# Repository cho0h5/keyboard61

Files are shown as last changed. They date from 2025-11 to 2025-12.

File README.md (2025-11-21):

# Keyboard Project

## Schematic

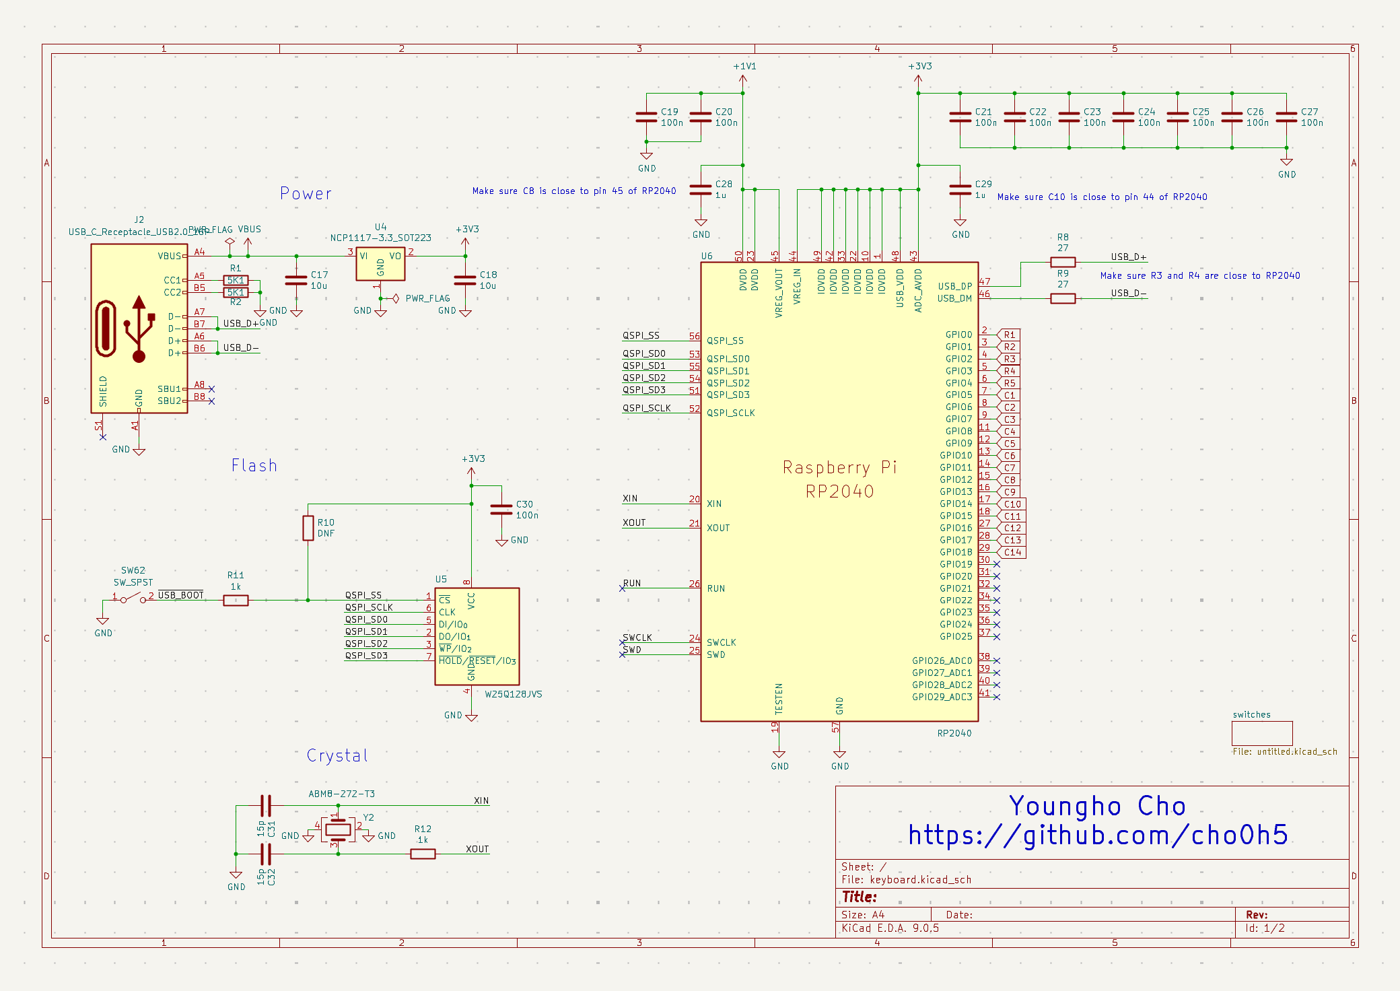
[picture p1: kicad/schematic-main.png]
Keyboard Schematic

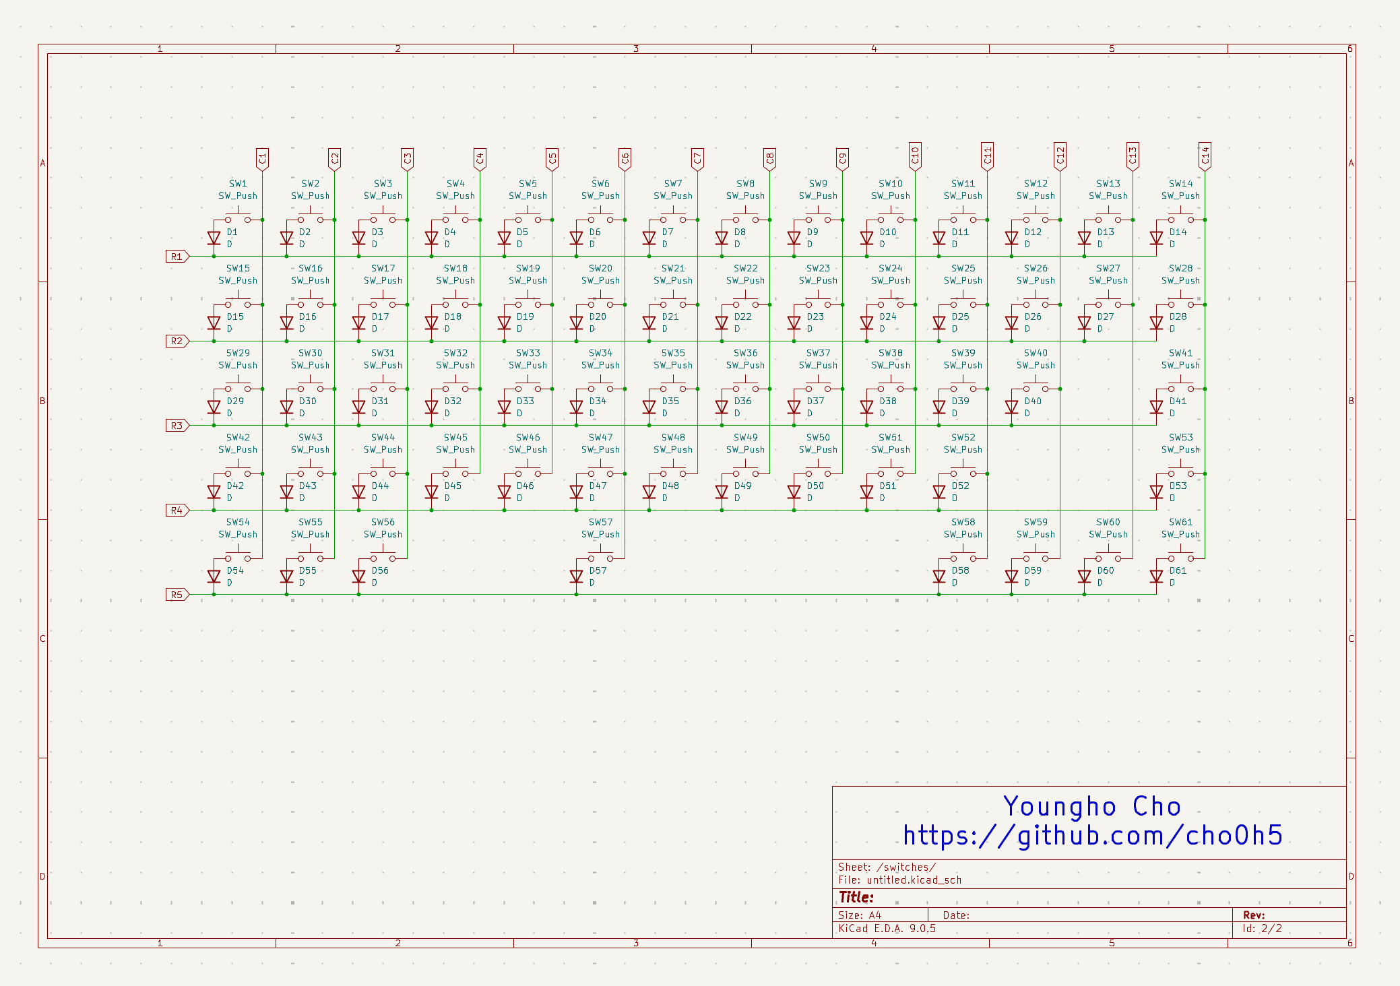
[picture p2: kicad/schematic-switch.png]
Keyboard Switches


## PCB Layout

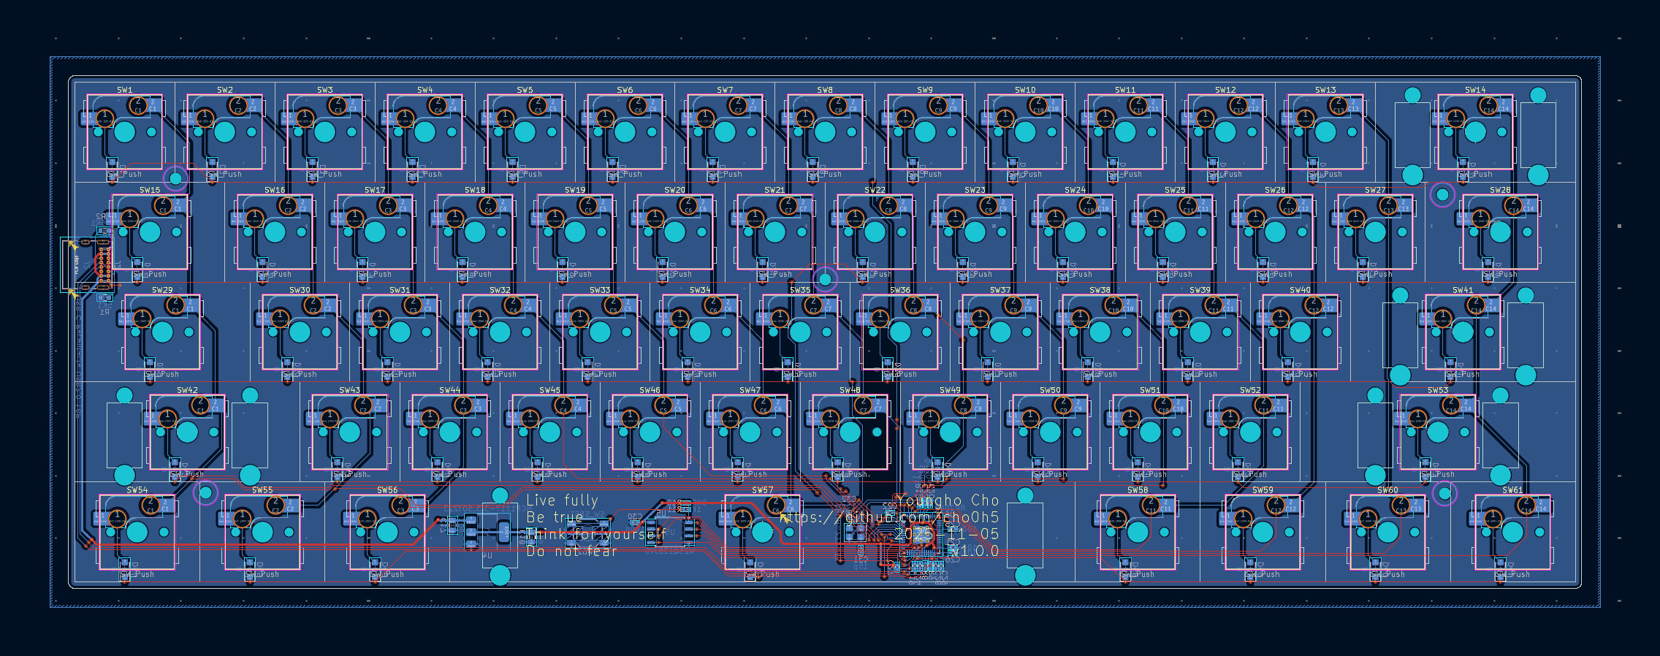
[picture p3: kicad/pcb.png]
PCB


## 3D Rendering

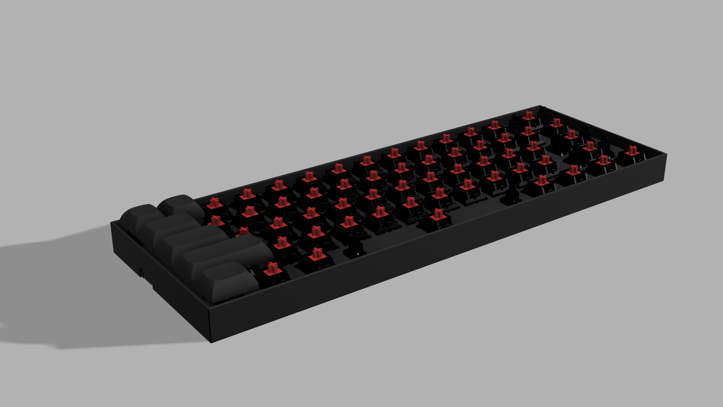
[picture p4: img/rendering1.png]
Rendering 1

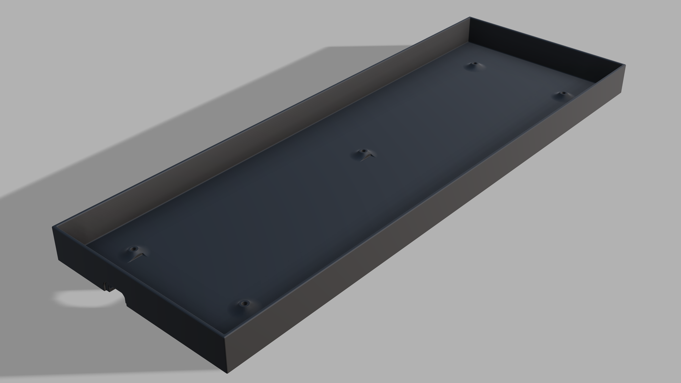
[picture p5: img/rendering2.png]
Rendering 2

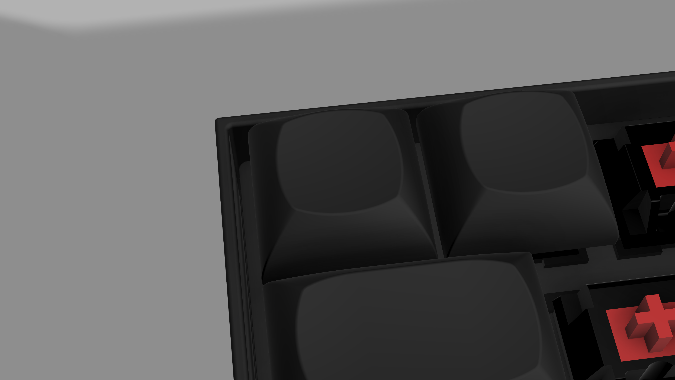
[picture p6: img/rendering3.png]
Rendering 3

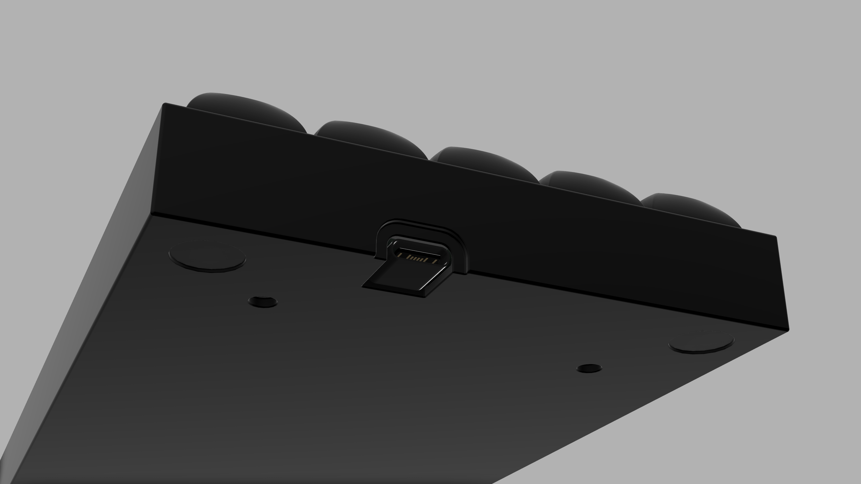
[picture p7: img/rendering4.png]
Rendering 4

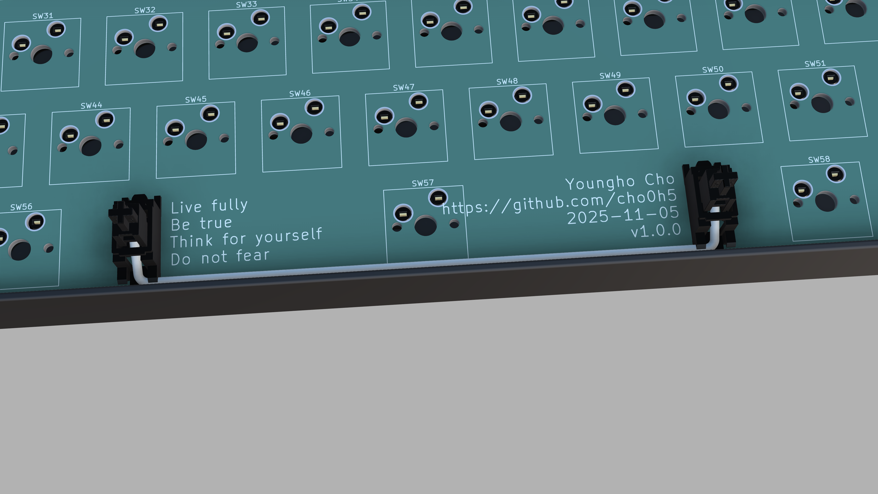
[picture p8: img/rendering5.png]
Rendering 5


## Actual Photos

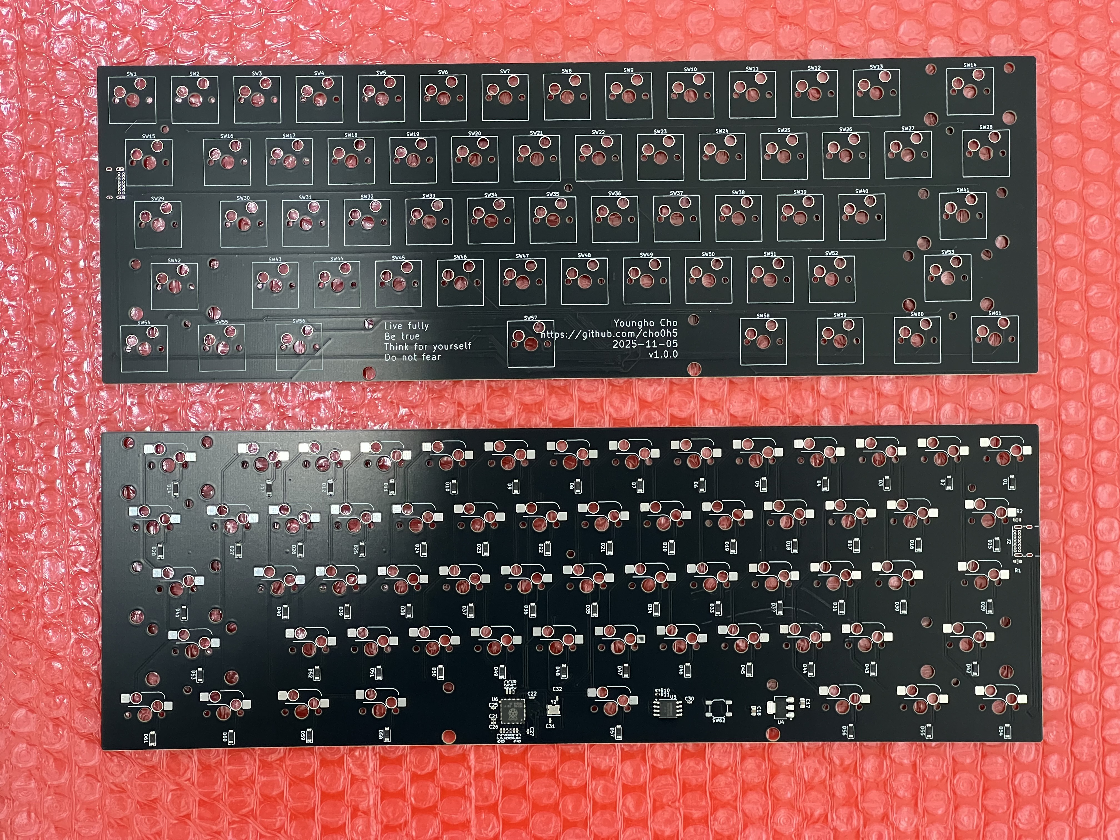
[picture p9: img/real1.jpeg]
Actual Photo 1

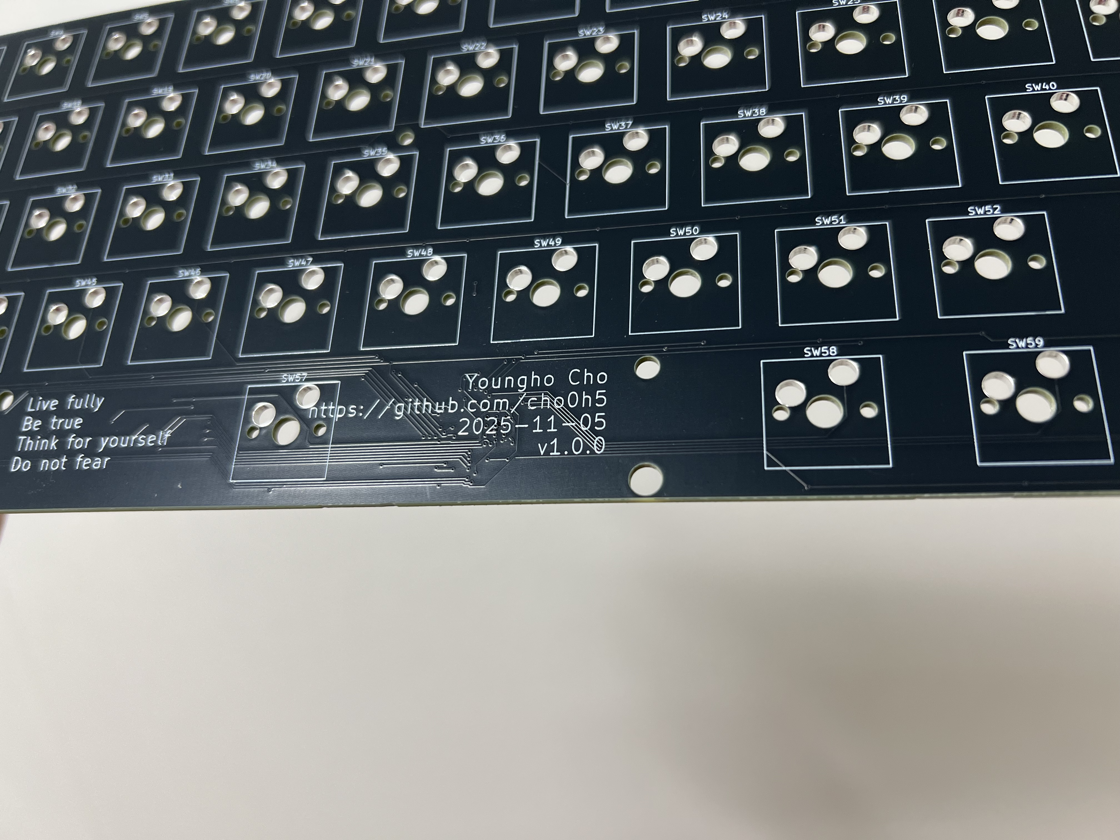
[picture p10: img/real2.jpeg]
Actual Photo 2

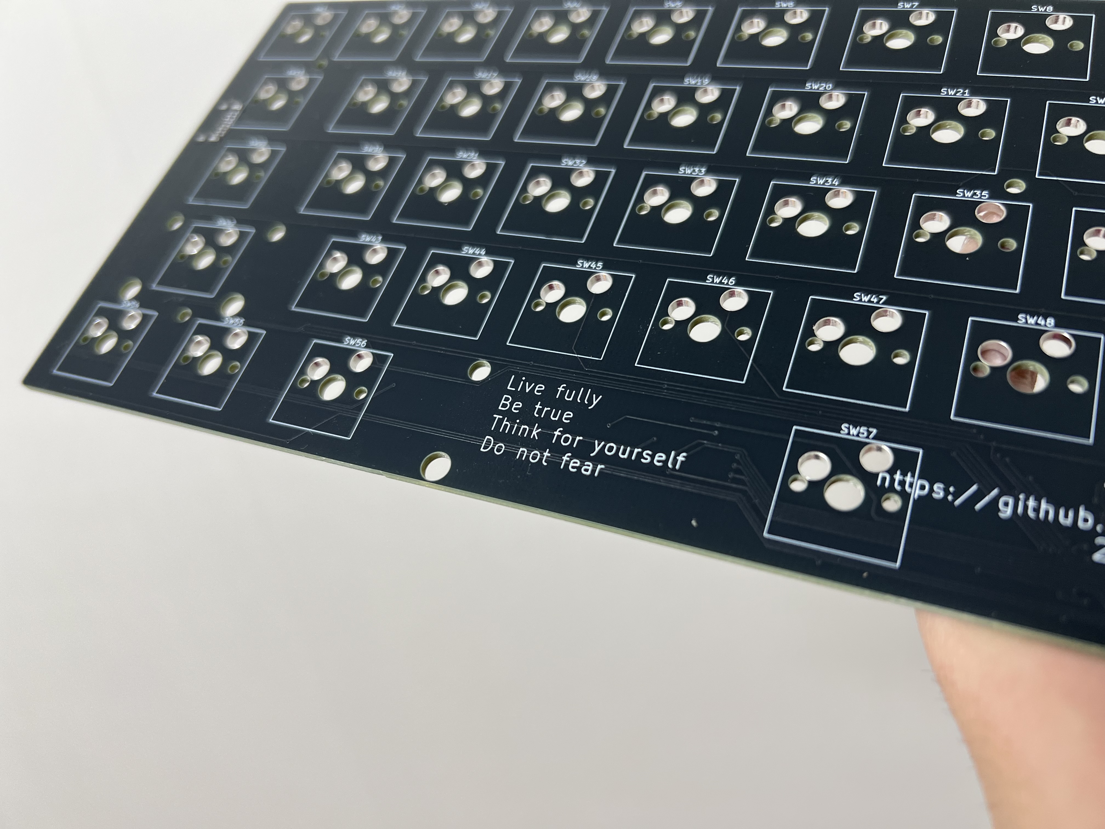
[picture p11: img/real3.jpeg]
Actual Photo 3

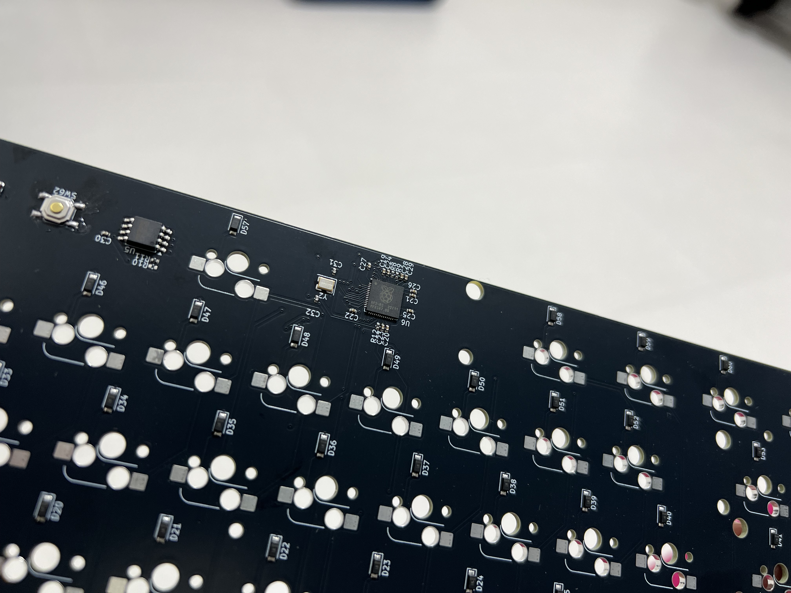
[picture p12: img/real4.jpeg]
Actual Photo 4

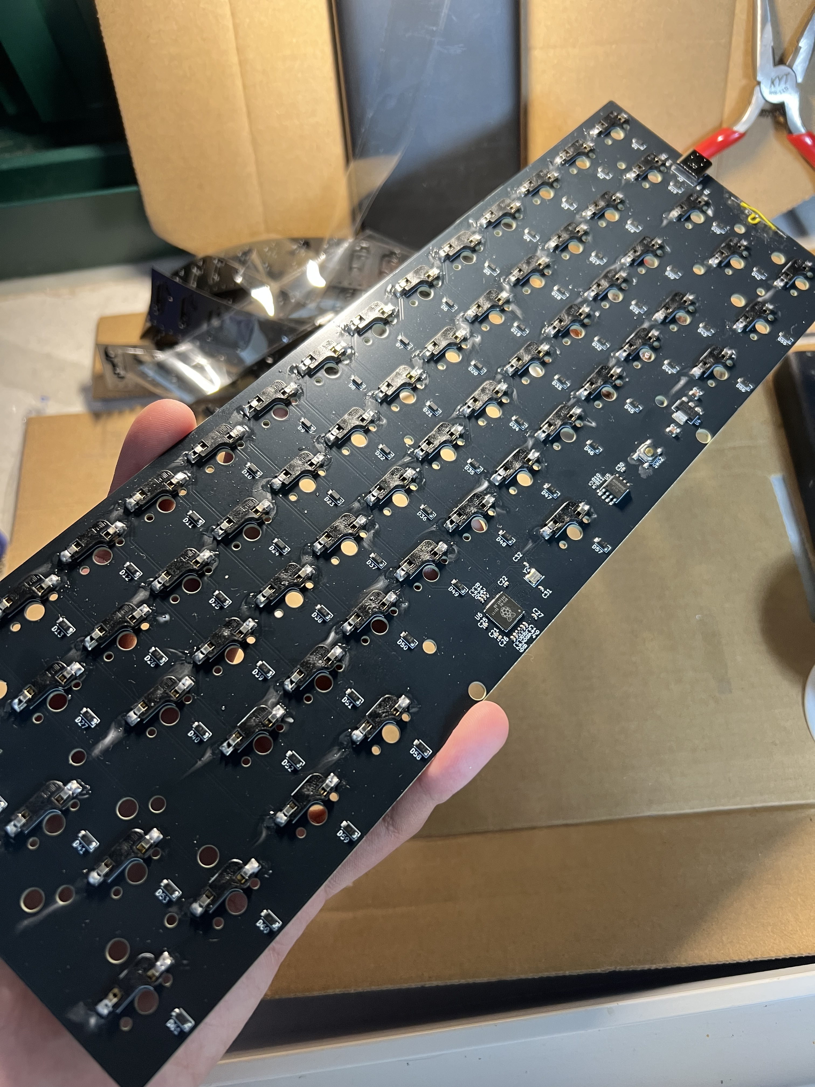
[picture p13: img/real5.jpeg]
Actual Photo 5

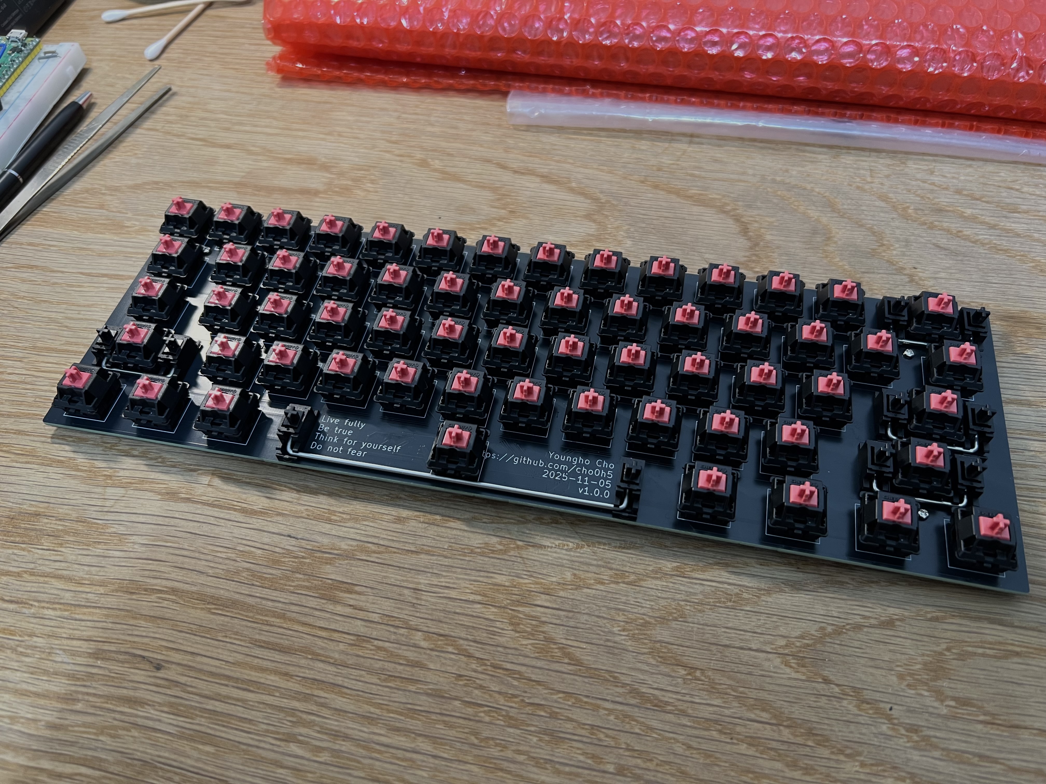
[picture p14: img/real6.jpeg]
Actual Photo 6


### 3D Models Used
- Cherry MX Switch: [ConstantinoSchillebeeckx/cherry-mx-switch](https://github.com/ConstantinoSchillebeeckx/cherry-mx-switch)
- DSA Keycap: [anhthang/dsa-keycap](https://github.com/anhthang/dsa-keycap)

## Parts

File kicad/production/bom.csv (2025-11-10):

Designator | Footprint | Quantity | Value | LCSC Part #
C17, C18 | 0805 | 2 | 10u
C19, C20, C21, C22, C23, C24, C25, C26, C27, C30 | 0402 | 10 | 100n
C28, C29 | 0402 | 2 | 1u
C31, C32 | 0402 | 2 | 15p
D1, D10, D11, D12, D13, D14, D15, D16, D17, D18, D19, D2, D20, D21, D22, D23, D24, D25, D26, D27, D28, D29, D3, D30, D31, D32, D33, D34, D35, D36, D37, D38, D39, D4, D40, D41, D42, D43, D44, D45, D46, D47, D48, D49, D5, D50, D51, D52, D53, D54, D55, D56, D57, D58, D59, D6, D60, D61, D7, D8, D9 | Nexperia_CFP3_SOD-123W | 61 | D
J2 | USB_C_Receptacle_GCT_USB4085 | 1 | USB_C_Receptacle_USB2.0_16P
R1, R2 | 0603 | 2 | 5K1
R10 | 0402 | 1 | DNF
R11, R12 | 0402 | 2 | 1k
R8, R9 | 0402 | 2 | 27
SW1, SW10, SW11, SW12, SW13, SW16, SW17, SW18, SW19, SW2, SW20, SW21, SW22, SW23, SW24, SW25, SW26, SW27, SW3, SW30, SW31, SW32, SW33, SW34, SW35, SW36, SW37, SW38, SW39, SW4, SW40, SW43, SW44, SW45, SW46, SW47, SW48, SW49, SW5, SW50, SW51, SW52, SW6, SW7, SW8, SW9 | SW_Hotswap_Kailh_MX_Plated_1.00u | 46 | SW_Push
SW14 | SW_Hotswap_Kailh_MX_Plated_2.00u | 1 | SW_Push
SW15, SW28 | SW_Hotswap_Kailh_MX_Plated_1.50u | 2 | SW_Push
SW29 | SW_Hotswap_Kailh_MX_Plated_1.75u | 1 | SW_Push
SW41, SW42 | SW_Hotswap_Kailh_MX_Plated_2.25u | 2 | SW_Push
SW53 | SW_Hotswap_Kailh_MX_Plated_2.75u | 1 | SW_Push
SW54, SW55, SW56, SW58, SW59, SW60, SW61 | SW_Hotswap_Kailh_MX_Plated_1.25u | 7 | SW_Push
SW57 | SW_Hotswap_Kailh_MX_Plated_6.25u | 1 | SW_Push
SW62 | SW_SPST_SKQG_WithoutStem | 1 | SW_SPST
U4 | SOT-223-3_TabPin2 | 1 | NCP1117-3.3_SOT223
U5 | SOIC-8_5.3x5.3mm_P1.27mm | 1 | W25Q128JVS
U6 | RP2040-QFN-56 | 1 | RP2040
Y2 | Crystal_SMD_3225-4Pin_3.2x2.5mm | 1 | ABM8-272-T3

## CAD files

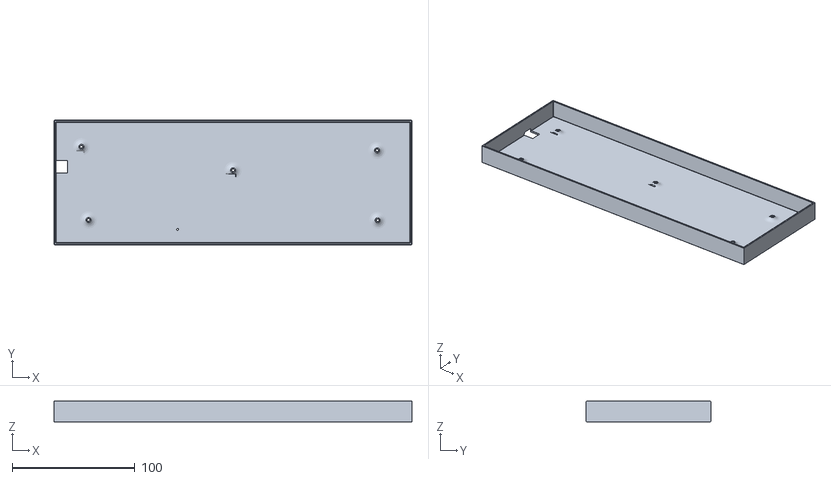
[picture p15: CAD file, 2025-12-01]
fusion/Outer.stl
292.1 x 101.6 x 17.0

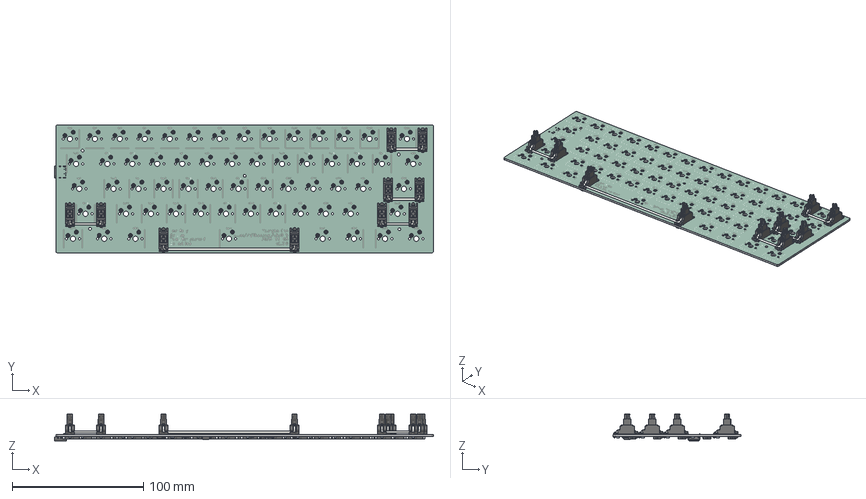
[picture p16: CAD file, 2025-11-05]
kicad/keyboard.step
289.1 x 97.9 x 20.6 mm
SW_Hotswap_Kailh_MX x 61
Stabilizer_Cherry_MX_2.00u x 4
Stabilizer_Cherry_MX_6.25u
keyboard 1.67.1 x 61
C_0402_1005Metric x 14
SW_SPST_SKQG_WithoutStem
R_0402_1005Metric x 5
R_0603_1608Metric x 2
C_0805_2012Metric x 2
SOIC-8_5.3x5.3mm_P1.27mm
SOT-223
Crystal_SMD_3225-4Pin_3.2x2.5mm
USB_C_Receptacle_GCT_USB4085
QFN-56-1EP_7x7mm_P0.4mm_EP5.6x5.6mm
keyboard_silkscreen x 2
keyboard_soldermask x 2
keyboard_PCB

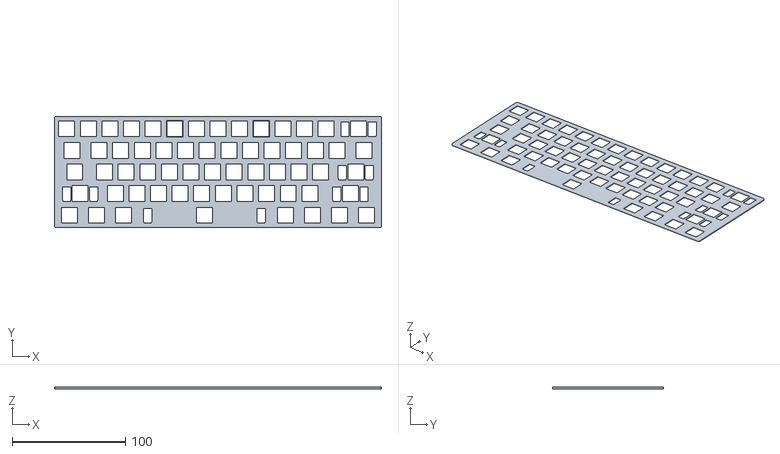
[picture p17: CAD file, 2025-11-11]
fusion/Plate.stl
288.1 x 97.6 x 1.50

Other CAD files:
fusion/Case.f3z

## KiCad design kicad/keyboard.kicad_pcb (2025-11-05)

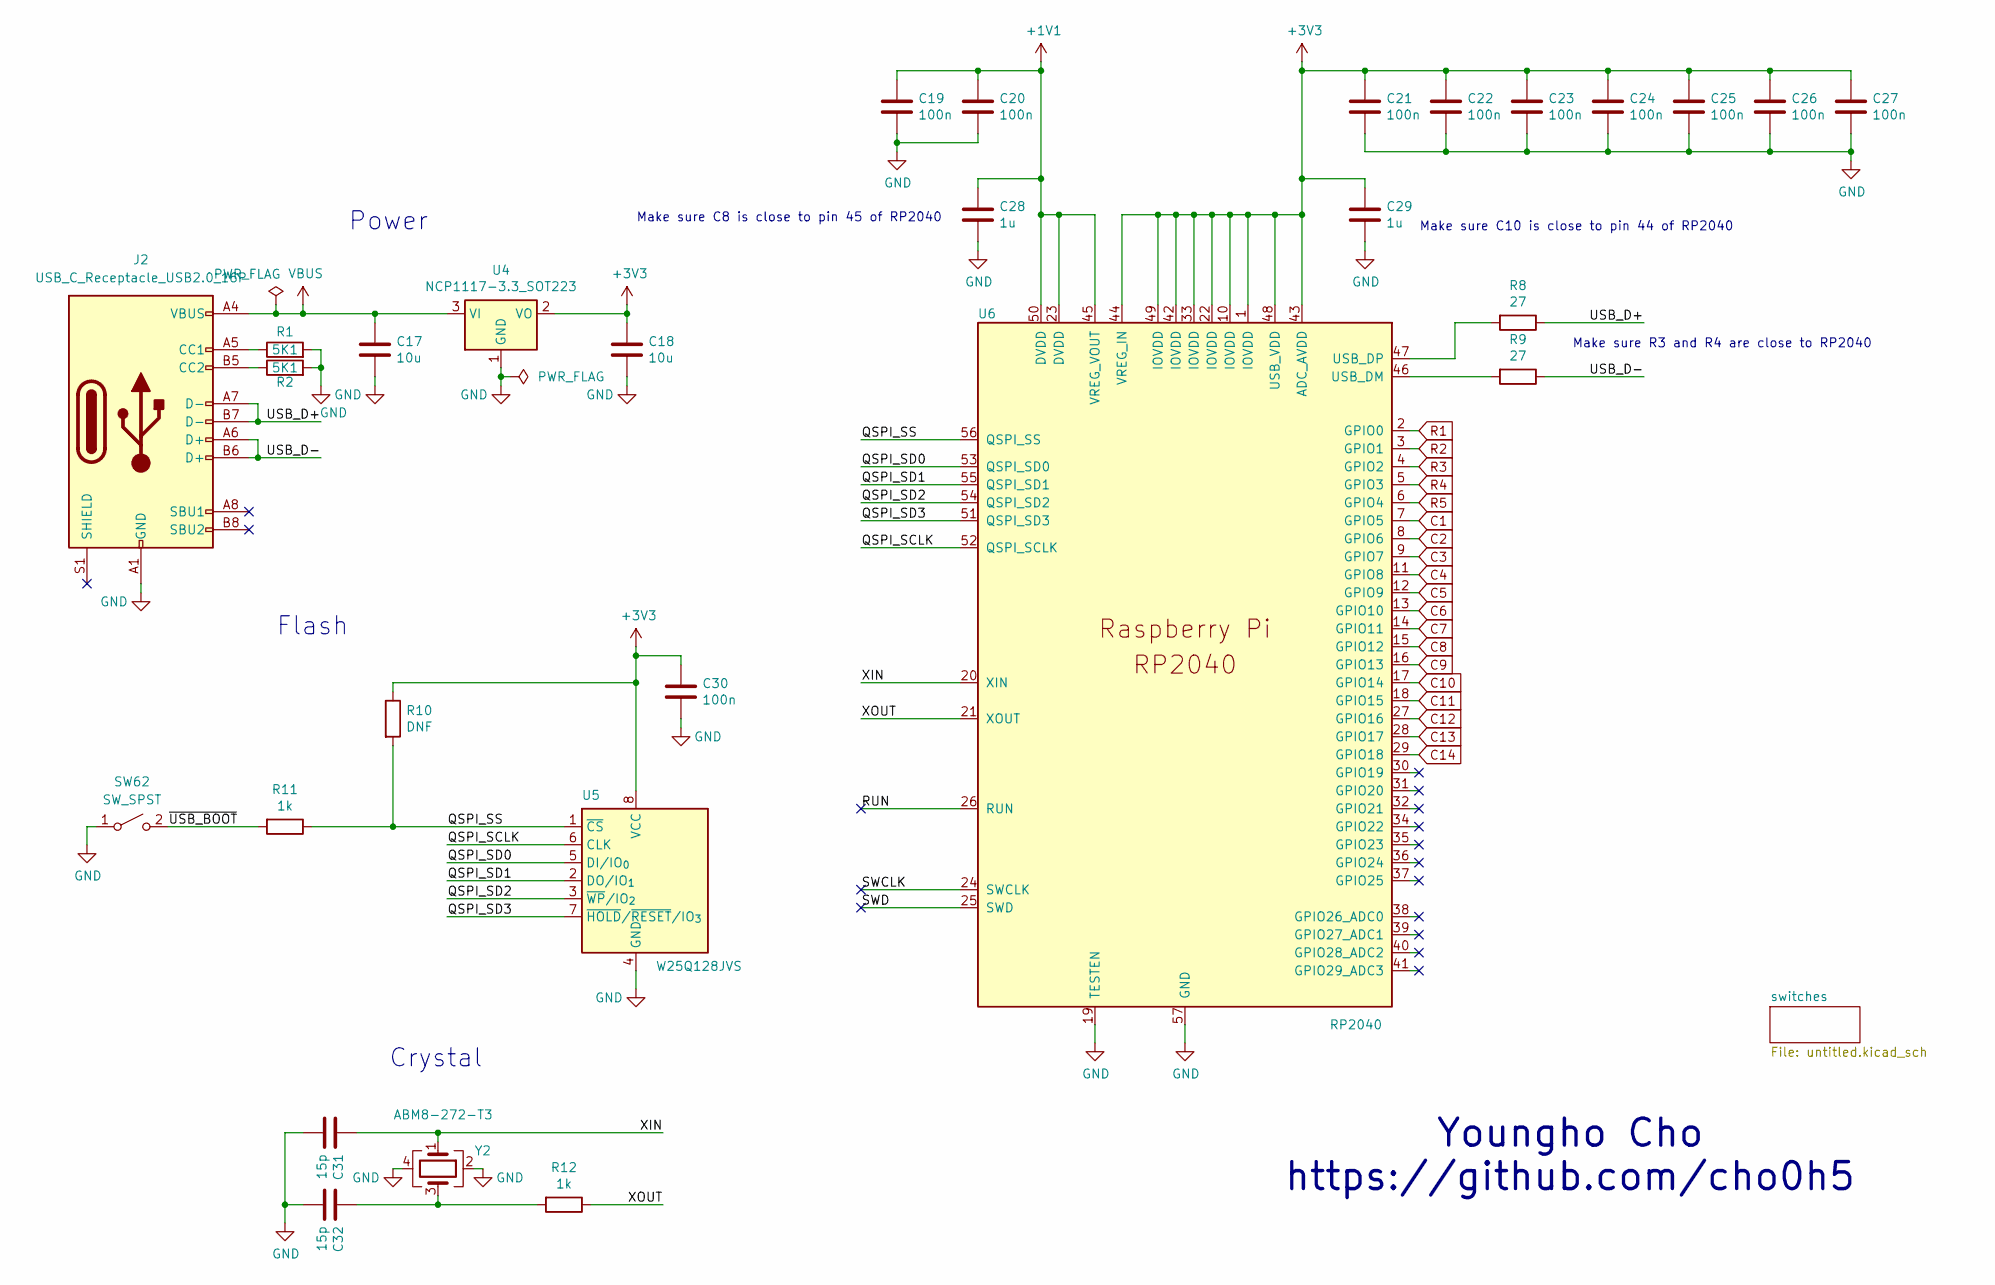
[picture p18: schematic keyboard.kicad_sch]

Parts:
C17, C18: 10u; C_0805_2012Metric
C19, C20, C21, C22, C23, C24, C25, C26, C27, C30: 100n; C_0402_1005Metric
C28, C29: 1u; C_0402_1005Metric
C31, C32: 15p; C_0402_1005Metric
J2: USB_C_Receptacle_USB2.0_16P; USB_C_Receptacle_GCT_USB4085
R1, R2: 5K1; R_0603_1608Metric
R8, R9: 27; R_0402_1005Metric
R10: DNF; R_0402_1005Metric
R11, R12: 1k; R_0402_1005Metric
SW62: SW_SPST; SW_SPST_SKQG_WithoutStem
U4: NCP1117-3.3_SOT223; SOT-223-3_TabPin2
U5: W25Q128JVS; SOIC-8_5.3x5.3mm_P1.27mm
U6: RP2040; RP2040-QFN-56
Y2: ABM8-272-T3; Crystal_SMD_3225-4Pin_3.2x2.5mm

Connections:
+1V1: C19.1, C20.1, C28.1, U6.23 (DVDD), U6.45 (VREG_VOUT), U6.50 (DVDD)
+3V3: C18.1, C21.1, C22.1, C23.1, C24.1, C25.1, C26.1, C27.1, C29.1, C30.1, R10.1, U4.2 (VO), U5.8 (VCC), U6.1 (IOVDD), U6.10 (IOVDD), U6.22 (IOVDD), U6.33 (IOVDD), U6.42 (IOVDD), U6.43 (ADC_AVDD), U6.44 (VREG_IN), U6.48 (USB_VDD), U6.49 (IOVDD)
/QSPI_SCLK: U5.6 (CLK), U6.52 (QSPI_SCLK)
/QSPI_SD0: U5.5 (DI/IO_{0}), U6.53 (QSPI_SD0)
/QSPI_SD1: U5.2 (DO/IO_{1}), U6.55 (QSPI_SD1)
/QSPI_SD2: U5.3 (~WP/IO_{2}), U6.54 (QSPI_SD2)
/QSPI_SD3: U5.7 (~HOLD/~RESET/IO_{3}), U6.51 (QSPI_SD3)
/QSPI_SS: R10.2, R11.1, U5.1 (~CS), U6.56 (QSPI_SS)
/RUN: U6.26 (RUN)
/SWCLK: U6.24 (SWCLK)
/SWD: U6.25 (SWD)
/USB_D+: J2.A7 (D-), J2.B7 (D-), R8.1
/USB_D-: J2.A6 (D+), J2.B6 (D+), R9.1
/XIN: C31.1, U6.20 (XIN), Y2.1
/XOUT: R12.1, U6.21 (XOUT)
/~USB_BOOT: R11.2, SW62.2 (B)
C1: U6.7 (GPIO5); also elsewhere on the board
C2: U6.8 (GPIO6); also elsewhere on the board
C3: U6.9 (GPIO7); also elsewhere on the board
C4: U6.11 (GPIO8); also elsewhere on the board
C5: U6.12 (GPIO9); also elsewhere on the board
C6: U6.13 (GPIO10); also elsewhere on the board
C7: U6.14 (GPIO11); also elsewhere on the board
C8: U6.15 (GPIO12); also elsewhere on the board
C9: U6.16 (GPIO13); also elsewhere on the board
C10: U6.17 (GPIO14); also elsewhere on the board
C11: U6.18 (GPIO15); also elsewhere on the board
C12: U6.27 (GPIO16); also elsewhere on the board
C13: U6.28 (GPIO17); also elsewhere on the board
C14: U6.29 (GPIO18); also elsewhere on the board
GND: C17.2, C18.2, C19.2, C20.2, C21.2, C22.2, C23.2, C24.2, C25.2, C26.2, C27.2, C28.2, C29.2, C30.2, C31.2, C32.2, J2.A1 (GND), J2.A12 (GND), J2.B1 (GND), J2.B12 (GND), R1.2, R2.2, SW62.1 (A), U4.1 (GND), U5.4 (GND), U6.19 (TESTEN), U6.57 (GND), Y2.2, Y2.4
unnamed: C32.1, R12.2, Y2.3
unnamed: J2.A5 (CC1), R1.1
unnamed: J2.B5 (CC2), R2.1
unnamed: R9.2, U6.46 (USB_DM)
unnamed: R8.2, U6.47 (USB_DP)
R1: U6.2 (GPIO0); also elsewhere on the board
R2: U6.3 (GPIO1); also elsewhere on the board
R3: U6.4 (GPIO2); also elsewhere on the board
R4: U6.5 (GPIO3); also elsewhere on the board
R5: U6.6 (GPIO4); also elsewhere on the board
VBUS: C17.1, J2.A4 (VBUS), J2.A9 (VBUS), J2.B4 (VBUS), J2.B9 (VBUS), U4.3 (VI)

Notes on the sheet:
Make sure C10 is close to pin 44 of RP2040
Flash
Crystal
Make sure C8 is close to pin 45 of RP2040
Make sure R3 and R4 are close to RP2040
Youngho Cho https://github.com/cho0h5
Power

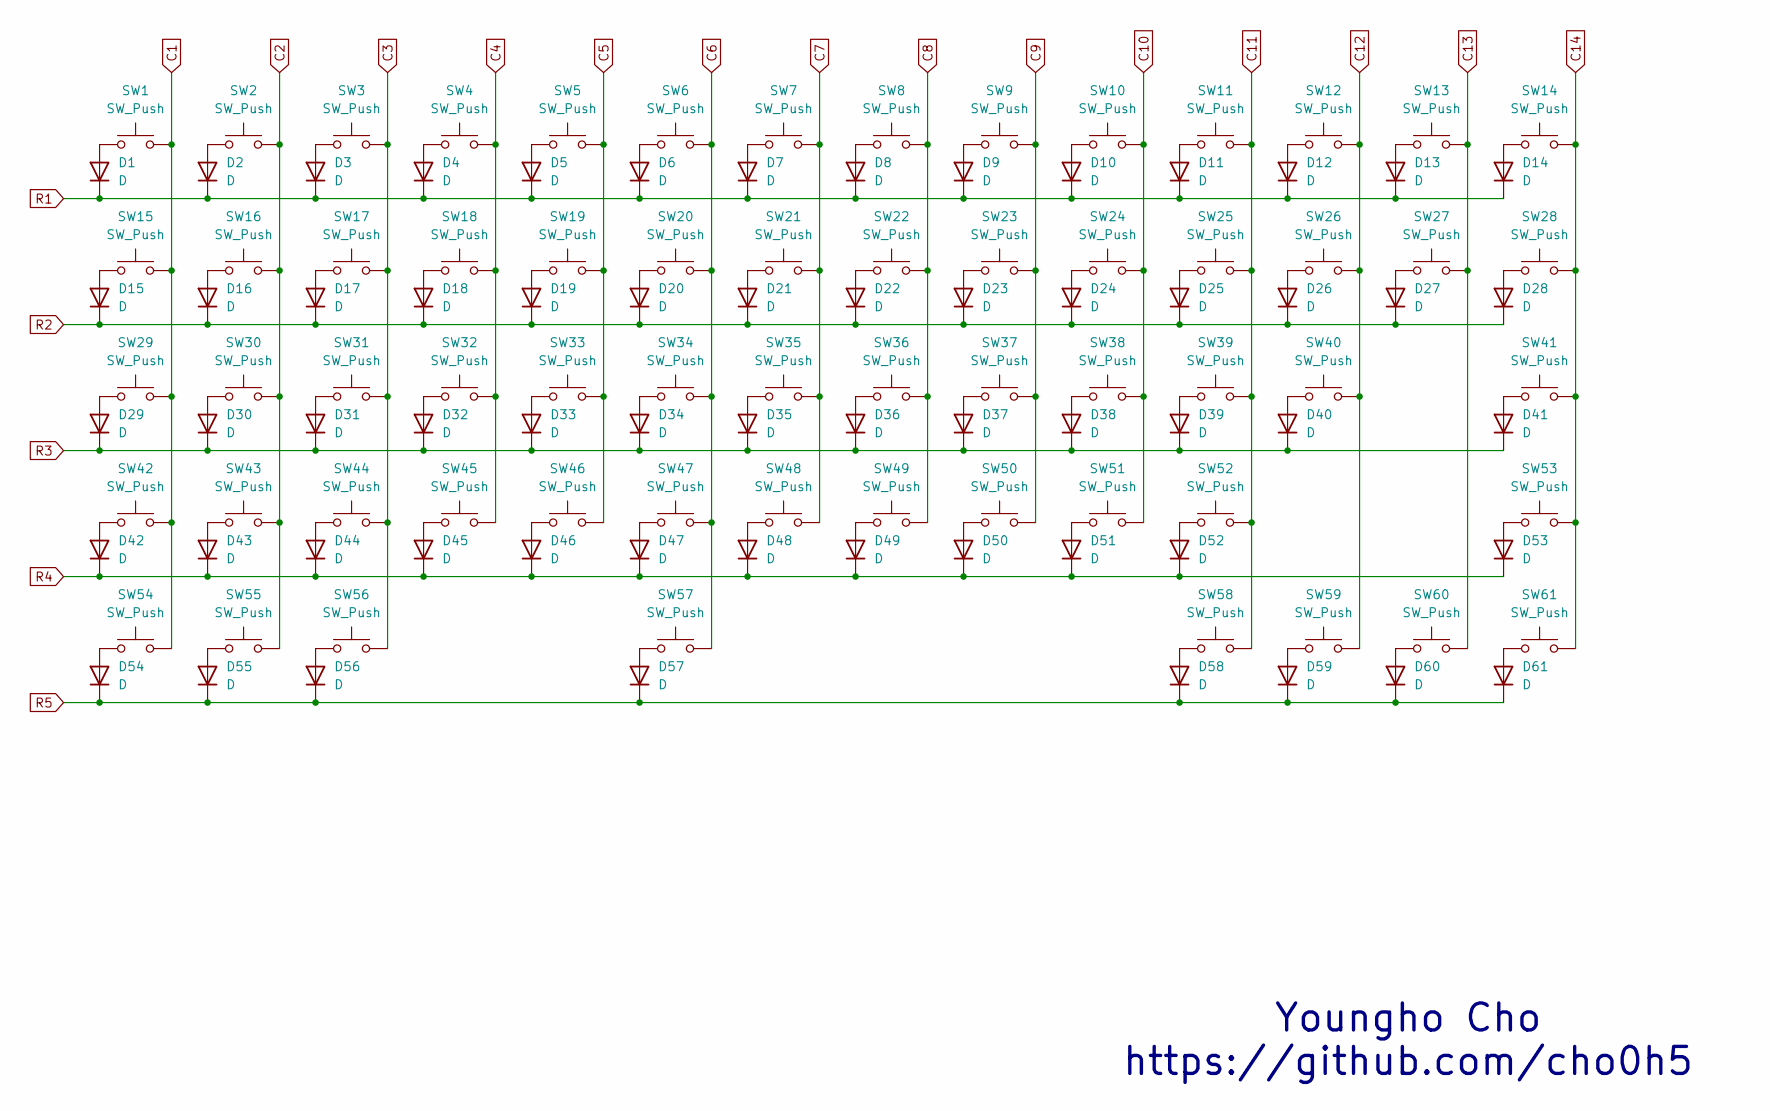
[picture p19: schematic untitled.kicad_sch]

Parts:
D1, D2, D3, D4, D5, D6, D7, D8, D9, D10, D11, D12, D13, D14, D15, D16, D17, D18, D19, D20, D21, D22, D23, D24, D25, D26, D27, D28, D29, D30, D31, D32, D33, D34, D35, D36, D37, D38, D39, D40, D41, D42, D43, D44, D45, D46, D47, D48, D49, D50, D51, D52, D53, D54, D55, D56, D57, D58, D59, D60, D61: D; Nexperia_CFP3_SOD-123W
SW1, SW2, SW3, SW4, SW5, SW6, SW7, SW8, SW9, SW10, SW11, SW12, SW13, SW16, SW17, SW18, SW19, SW20, SW21, SW22, SW23, SW24, SW25, SW26, SW27, SW30, SW31, SW32, SW33, SW34, SW35, SW36, SW37, SW38, SW39, SW40, SW43, SW44, SW45, SW46, SW47, SW48, SW49, SW50, SW51, SW52: SW_Push; SW_Hotswap_Kailh_MX_Plated_1.00u
SW14: SW_Push; SW_Hotswap_Kailh_MX_Plated_2.00u
SW15, SW28: SW_Push; SW_Hotswap_Kailh_MX_Plated_1.50u
SW29: SW_Push; SW_Hotswap_Kailh_MX_Plated_1.75u
SW41, SW42: SW_Push; SW_Hotswap_Kailh_MX_Plated_2.25u
SW53: SW_Push; SW_Hotswap_Kailh_MX_Plated_2.75u
SW54, SW55, SW56, SW58, SW59, SW60, SW61: SW_Push; SW_Hotswap_Kailh_MX_Plated_1.25u
SW57: SW_Push; SW_Hotswap_Kailh_MX_Plated_6.25u

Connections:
C1: SW1.2, SW15.2, SW29.2, SW42.2, SW54.2; also elsewhere on the board
C2: SW2.2, SW16.2, SW30.2, SW43.2, SW55.2; also elsewhere on the board
C3: SW3.2, SW17.2, SW31.2, SW44.2, SW56.2; also elsewhere on the board
C4: SW4.2, SW18.2, SW32.2, SW45.2; also elsewhere on the board
C5: SW5.2, SW19.2, SW33.2, SW46.2; also elsewhere on the board
C6: SW6.2, SW20.2, SW34.2, SW47.2, SW57.2; also elsewhere on the board
C7: SW7.2, SW21.2, SW35.2, SW48.2; also elsewhere on the board
C8: SW8.2, SW22.2, SW36.2, SW49.2; also elsewhere on the board
C9: SW9.2, SW23.2, SW37.2, SW50.2; also elsewhere on the board
C10: SW10.2, SW24.2, SW38.2, SW51.2; also elsewhere on the board
C11: SW11.2, SW25.2, SW39.2, SW52.2, SW58.2; also elsewhere on the board
C12: SW12.2, SW26.2, SW40.2, SW59.2; also elsewhere on the board
C13: SW13.2, SW27.2, SW60.2; also elsewhere on the board
C14: SW14.2, SW28.2, SW41.2, SW53.2, SW61.2; also elsewhere on the board
unnamed: D1.2 (A), SW1.1
unnamed: D2.2 (A), SW2.1
unnamed: D3.2 (A), SW3.1
unnamed: D4.2 (A), SW4.1
unnamed: D5.2 (A), SW5.1
unnamed: D6.2 (A), SW6.1
unnamed: D7.2 (A), SW7.1
unnamed: D8.2 (A), SW8.1
unnamed: D9.2 (A), SW9.1
unnamed: D10.2 (A), SW10.1
unnamed: D11.2 (A), SW11.1
unnamed: D12.2 (A), SW12.1
unnamed: D13.2 (A), SW13.1
unnamed: D14.2 (A), SW14.1
unnamed: D15.2 (A), SW15.1
unnamed: D16.2 (A), SW16.1
unnamed: D17.2 (A), SW17.1
unnamed: D18.2 (A), SW18.1
unnamed: D19.2 (A), SW19.1
unnamed: D20.2 (A), SW20.1
unnamed: D21.2 (A), SW21.1
unnamed: D22.2 (A), SW22.1
unnamed: D23.2 (A), SW23.1
unnamed: D24.2 (A), SW24.1
unnamed: D25.2 (A), SW25.1
unnamed: D26.2 (A), SW26.1
unnamed: D27.2 (A), SW27.1
unnamed: D28.2 (A), SW28.1
unnamed: D29.2 (A), SW29.1
unnamed: D30.2 (A), SW30.1
unnamed: D31.2 (A), SW31.1
unnamed: D32.2 (A), SW32.1
unnamed: D33.2 (A), SW33.1
unnamed: D34.2 (A), SW34.1
unnamed: D35.2 (A), SW35.1
unnamed: D36.2 (A), SW36.1
unnamed: D37.2 (A), SW37.1
unnamed: D38.2 (A), SW38.1
unnamed: D39.2 (A), SW39.1
unnamed: D40.2 (A), SW40.1
unnamed: D41.2 (A), SW41.1
unnamed: D42.2 (A), SW42.1
unnamed: D43.2 (A), SW43.1
unnamed: D44.2 (A), SW44.1
unnamed: D45.2 (A), SW45.1
unnamed: D46.2 (A), SW46.1
unnamed: D47.2 (A), SW47.1
unnamed: D48.2 (A), SW48.1
unnamed: D49.2 (A), SW49.1
unnamed: D50.2 (A), SW50.1
unnamed: D51.2 (A), SW51.1
unnamed: D52.2 (A), SW52.1
unnamed: D53.2 (A), SW53.1
unnamed: D54.2 (A), SW54.1
unnamed: D55.2 (A), SW55.1
unnamed: D56.2 (A), SW56.1
unnamed: D57.2 (A), SW57.1
unnamed: D58.2 (A), SW58.1
unnamed: D59.2 (A), SW59.1
unnamed: D60.2 (A), SW60.1
unnamed: D61.2 (A), SW61.1
R1: D1.1 (K), D2.1 (K), D3.1 (K), D4.1 (K), D5.1 (K), D6.1 (K), D7.1 (K), D8.1 (K), D9.1 (K), D10.1 (K), D11.1 (K), D12.1 (K), D13.1 (K), D14.1 (K); also elsewhere on the board
R2: D15.1 (K), D16.1 (K), D17.1 (K), D18.1 (K), D19.1 (K), D20.1 (K), D21.1 (K), D22.1 (K), D23.1 (K), D24.1 (K), D25.1 (K), D26.1 (K), D27.1 (K), D28.1 (K); also elsewhere on the board
R3: D29.1 (K), D30.1 (K), D31.1 (K), D32.1 (K), D33.1 (K), D34.1 (K), D35.1 (K), D36.1 (K), D37.1 (K), D38.1 (K), D39.1 (K), D40.1 (K), D41.1 (K); also elsewhere on the board
R4: D42.1 (K), D43.1 (K), D44.1 (K), D45.1 (K), D46.1 (K), D47.1 (K), D48.1 (K), D49.1 (K), D50.1 (K), D51.1 (K), D52.1 (K), D53.1 (K); also elsewhere on the board
R5: D54.1 (K), D55.1 (K), D56.1 (K), D57.1 (K), D58.1 (K), D59.1 (K), D60.1 (K), D61.1 (K); also elsewhere on the board

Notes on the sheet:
Youngho Cho https://github.com/cho0h5

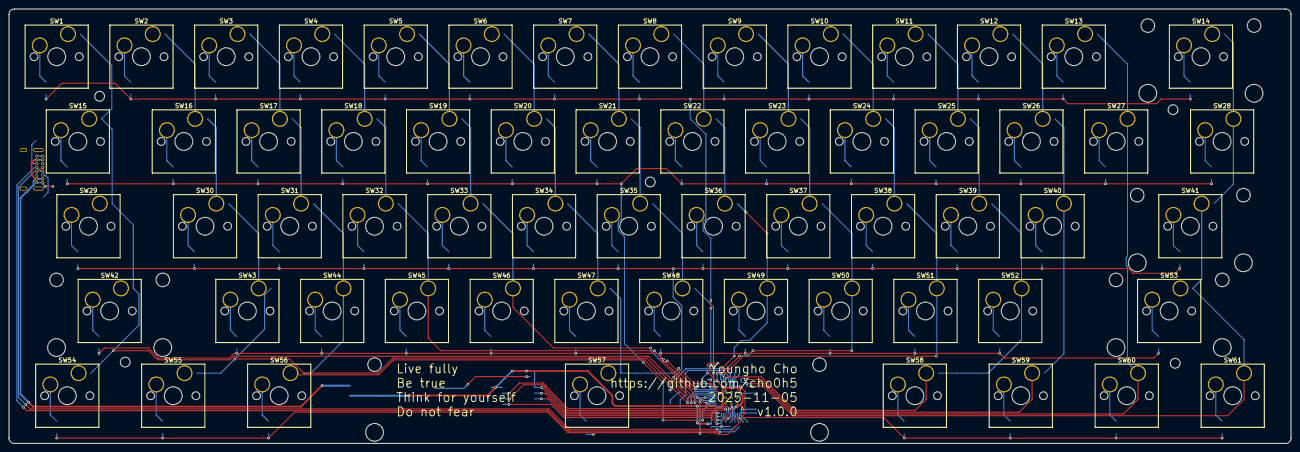
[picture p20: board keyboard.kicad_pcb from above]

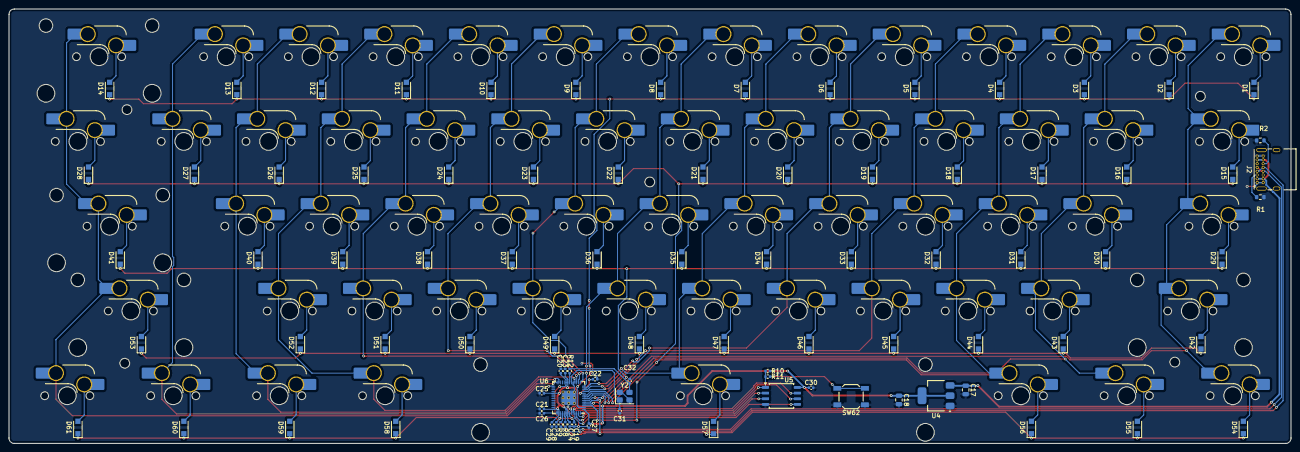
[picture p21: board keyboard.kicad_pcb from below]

Board: 2 copper layers, 288.1 x 97.6 mm, 151 parts (90 on the bottom side), 100 nets.

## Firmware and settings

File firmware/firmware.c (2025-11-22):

#include <stdio.h>
#include "pico/stdlib.h"

#include "bsp/board_api.h"
#include "tusb.h"

// HID Keycodes - Standard US Keyboard Layout
#define HID_KEY_NONE        0x00
#define HID_KEY_A           0x04
#define HID_KEY_B           0x05
#define HID_KEY_C           0x06
#define HID_KEY_D           0x07
#define HID_KEY_E           0x08
#define HID_KEY_F           0x09
#define HID_KEY_G           0x0A
#define HID_KEY_H           0x0B
#define HID_KEY_I           0x0C
#define HID_KEY_J           0x0D
#define HID_KEY_K           0x0E
#define HID_KEY_L           0x0F
#define HID_KEY_M           0x10
#define HID_KEY_N           0x11
#define HID_KEY_O           0x12
#define HID_KEY_P           0x13
#define HID_KEY_Q           0x14
#define HID_KEY_R           0x15
#define HID_KEY_S           0x16
#define HID_KEY_T           0x17
#define HID_KEY_U           0x18
#define HID_KEY_V           0x19
#define HID_KEY_W           0x1A
#define HID_KEY_X           0x1B
#define HID_KEY_Y           0x1C
#define HID_KEY_Z           0x1D
#define HID_KEY_1           0x1E
#define HID_KEY_2           0x1F
#define HID_KEY_3           0x20
#define HID_KEY_4           0x21
#define HID_KEY_5           0x22
#define HID_KEY_6           0x23
#define HID_KEY_7           0x24
#define HID_KEY_8           0x25
#define HID_KEY_9           0x26
#define HID_KEY_0           0x27
#define HID_KEY_ENTER       0x28
#define HID_KEY_ESCAPE      0x29
#define HID_KEY_BACKSPACE   0x2A
#define HID_KEY_TAB         0x2B
#define HID_KEY_SPACE       0x2C
#define HID_KEY_MINUS       0x2D
#define HID_KEY_EQUAL       0x2E
#define HID_KEY_BRACKET_LEFT  0x2F
#define HID_KEY_BRACKET_RIGHT 0x30
#define HID_KEY_BACKSLASH   0x31
#define HID_KEY_SEMICOLON   0x33
#define HID_KEY_APOSTROPHE  0x34
#define HID_KEY_GRAVE       0x35
#define HID_KEY_COMMA       0x36
#define HID_KEY_PERIOD      0x37
#define HID_KEY_SLASH       0x38
#define HID_KEY_CAPS_LOCK   0x39
#define HID_KEY_F1          0x3A
#define HID_KEY_F2          0x3B
#define HID_KEY_F3          0x3C
#define HID_KEY_F4          0x3D
#define HID_KEY_F5          0x3E
#define HID_KEY_F6          0x3F
#define HID_KEY_F7          0x40
#define HID_KEY_F8          0x41
#define HID_KEY_F9          0x42
#define HID_KEY_F10         0x43
#define HID_KEY_F11         0x44
#define HID_KEY_F12         0x45
#define HID_KEY_PRINT_SCREEN 0x46
#define HID_KEY_SCROLL_LOCK 0x47
#define HID_KEY_PAUSE       0x48
#define HID_KEY_INSERT      0x49
#define HID_KEY_HOME        0x4A
#define HID_KEY_PAGE_UP     0x4B
#define HID_KEY_DELETE      0x4C
#define HID_KEY_END         0x4D
#define HID_KEY_PAGE_DOWN   0x4E
#define HID_KEY_ARROW_RIGHT 0x4F
#define HID_KEY_ARROW_LEFT  0x50
#define HID_KEY_ARROW_DOWN  0x51
#define HID_KEY_ARROW_UP    0x52
#define HID_KEY_CONTROL_LEFT  0xE0
#define HID_KEY_SHIFT_LEFT    0xE1
#define HID_KEY_ALT_LEFT      0xE2
#define HID_KEY_GUI_LEFT      0xE3
#define HID_KEY_CONTROL_RIGHT 0xE4
#define HID_KEY_SHIFT_RIGHT   0xE5
#define HID_KEY_ALT_RIGHT     0xE6
#define HID_KEY_GUI_RIGHT     0xE7
#define HID_KEY_FN            0xF0  // Custom FN key

// Pin definitions
#define LED_PIN PICO_DEFAULT_LED_PIN

// Matrix configuration - 5 rows x 14 columns (61 keys)
#define NUM_ROWS 5
#define NUM_COLS 14

// Row pins: GPIO0-4 (connected to R1-R5 via pins 2-6)
#define ROW1_PIN 0  // GPIO0 -> Pin 2 -> R1
#define ROW2_PIN 1  // GPIO1 -> Pin 3 -> R2
#define ROW3_PIN 2  // GPIO2 -> Pin 4 -> R3
#define ROW4_PIN 3  // GPIO3 -> Pin 5 -> R4
#define ROW5_PIN 4  // GPIO4 -> Pin 6 -> R5

// Column pins: GPIO5-18 (connected to C1-C14)
#define COL1_PIN  5   // GPIO5  -> Pin 7  -> C1
#define COL2_PIN  6   // GPIO6  -> Pin 8  -> C2
#define COL3_PIN  7   // GPIO7  -> Pin 9  -> C3
#define COL4_PIN  8   // GPIO8  -> Pin 11 -> C4
#define COL5_PIN  9   // GPIO9  -> Pin 12 -> C5
#define COL6_PIN  10  // GPIO10 -> Pin 13 -> C6
#define COL7_PIN  11  // GPIO11 -> Pin 14 -> C7
#define COL8_PIN  12  // GPIO12 -> Pin 15 -> C8
#define COL9_PIN  13  // GPIO13 -> Pin 16 -> C9
#define COL10_PIN 14  // GPIO14 -> Pin 17 -> C10
#define COL11_PIN 15  // GPIO15 -> Pin 18 -> C11
#define COL12_PIN 16  // GPIO16 -> Pin 27 -> C12
#define COL13_PIN 17  // GPIO17 -> Pin 28 -> C13
#define COL14_PIN 18  // GPIO18 -> Pin 29 -> C14

// Pin arrays
const uint8_t row_pins[NUM_ROWS] = {ROW1_PIN, ROW2_PIN, ROW3_PIN, ROW4_PIN, ROW5_PIN};
const uint8_t col_pins[NUM_COLS] = {COL1_PIN, COL2_PIN, COL3_PIN, COL4_PIN, COL5_PIN, COL6_PIN, COL7_PIN, COL8_PIN, COL9_PIN, COL10_PIN, COL11_PIN, COL12_PIN, COL13_PIN, COL14_PIN};

// Keymap: [row][col] - Standard 60% keyboard layout
// Columns: C1(GPIO5), C2(GPIO6), C3(GPIO7), C4(GPIO8), C5(GPIO9), C6(GPIO10), C7(GPIO11), C8(GPIO12), C9(GPIO13), C10(GPIO14), C11(GPIO15), C12(GPIO16), C13(GPIO17), C14(GPIO18)
const uint8_t keymap[NUM_ROWS][NUM_COLS] = {
    // Row 1 (R1 - GPIO0): Number row
    {HID_KEY_GRAVE, HID_KEY_1, HID_KEY_2, HID_KEY_3, HID_KEY_4, HID_KEY_5, HID_KEY_6, HID_KEY_7, HID_KEY_8, HID_KEY_9, HID_KEY_0, HID_KEY_MINUS, HID_KEY_EQUAL, HID_KEY_BACKSPACE},

    // Row 2 (R2 - GPIO1): Top letter row
    {HID_KEY_TAB, HID_KEY_Q, HID_KEY_W, HID_KEY_E, HID_KEY_R, HID_KEY_T, HID_KEY_Y, HID_KEY_U, HID_KEY_I, HID_KEY_O, HID_KEY_P, HID_KEY_BRACKET_LEFT, HID_KEY_BRACKET_RIGHT, HID_KEY_BACKSLASH},

    // Row 3 (R3 - GPIO2): Home row
    {HID_KEY_CONTROL_LEFT, HID_KEY_A, HID_KEY_S, HID_KEY_D, HID_KEY_F, HID_KEY_G, HID_KEY_H, HID_KEY_J, HID_KEY_K, HID_KEY_L, HID_KEY_SEMICOLON, HID_KEY_APOSTROPHE, HID_KEY_NONE, HID_KEY_ENTER},

    // Row 4 (R4 - GPIO3): Bottom letter row
    {HID_KEY_SHIFT_LEFT, HID_KEY_Z, HID_KEY_X, HID_KEY_C, HID_KEY_V, HID_KEY_B, HID_KEY_N, HID_KEY_M, HID_KEY_COMMA, HID_KEY_PERIOD, HID_KEY_SLASH, HID_KEY_NONE, HID_KEY_NONE, HID_KEY_SHIFT_RIGHT},

    // Row 5 (R5 - GPIO4): Bottom modifier row
    {HID_KEY_FN, HID_KEY_GUI_LEFT, HID_KEY_ALT_LEFT, HID_KEY_NONE, HID_KEY_NONE, HID_KEY_SPACE, HID_KEY_NONE, HID_KEY_NONE, HID_KEY_NONE, HID_KEY_NONE, HID_KEY_ARROW_LEFT, HID_KEY_ARROW_DOWN, HID_KEY_ARROW_UP, HID_KEY_ARROW_RIGHT}
};

// FN Layer: When FN key is pressed
const uint8_t fn_keymap[NUM_ROWS][NUM_COLS] = {
    // Row 1 (R1 - GPIO0): Function keys
    {HID_KEY_ESCAPE, HID_KEY_F1, HID_KEY_F2, HID_KEY_F3, HID_KEY_F4, HID_KEY_F5, HID_KEY_F6, HID_KEY_F7, HID_KEY_F8, HID_KEY_F9, HID_KEY_F10, HID_KEY_F11, HID_KEY_F12, HID_KEY_DELETE},

    // Row 2 (R2 - GPIO1): Top letter row
    {HID_KEY_TAB, HID_KEY_Q, HID_KEY_W, HID_KEY_E, HID_KEY_R, HID_KEY_T, HID_KEY_Y, HID_KEY_U, HID_KEY_I, HID_KEY_O, HID_KEY_P, HID_KEY_BRACKET_LEFT, HID_KEY_BRACKET_RIGHT, HID_KEY_BACKSLASH},

    // Row 3 (R3 - GPIO2): Home row
    {HID_KEY_CONTROL_LEFT, HID_KEY_A, HID_KEY_S, HID_KEY_D, HID_KEY_F, HID_KEY_G, HID_KEY_H, HID_KEY_J, HID_KEY_K, HID_KEY_L, HID_KEY_SEMICOLON, HID_KEY_APOSTROPHE, HID_KEY_NONE, HID_KEY_ENTER},

    // Row 4 (R4 - GPIO3): Bottom letter row
    {HID_KEY_SHIFT_LEFT, HID_KEY_Z, HID_KEY_X, HID_KEY_C, HID_KEY_V, HID_KEY_B, HID_KEY_N, HID_KEY_M, HID_KEY_COMMA, HID_KEY_PERIOD, HID_KEY_SLASH, HID_KEY_NONE, HID_KEY_NONE, HID_KEY_SHIFT_RIGHT},

    // Row 5 (R5 - GPIO4): Bottom modifier row
    {HID_KEY_FN, HID_KEY_GUI_LEFT, HID_KEY_ALT_LEFT, HID_KEY_NONE, HID_KEY_NONE, HID_KEY_SPACE, HID_KEY_NONE, HID_KEY_NONE, HID_KEY_NONE, HID_KEY_NONE, HID_KEY_ARROW_LEFT, HID_KEY_ARROW_DOWN, HID_KEY_ARROW_UP, HID_KEY_ARROW_RIGHT}
};

// Check if FN key is pressed
bool is_fn_pressed(void)
{
    // FN key is at Row 5 (index 4), Column 1 (index 0)
    gpio_put(row_pins[4], 0);  // Set Row 5 LOW
    sleep_us(1);
    bool fn_pressed = !gpio_get(col_pins[0]);  // Check Column 1
    gpio_put(row_pins[4], 1);  // Set Row 5 back to HIGH
    return fn_pressed;
}

// Scan matrix and collect all pressed keys
// 회로도: ROW -> 다이오드 -> 스위치 -> COLUMN
// 스캔 방식: ROW를 LOW로 설정하고 COLUMN을 읽음
// Returns number of keys pressed
uint8_t scan_matrix(uint8_t* keycodes, uint8_t max_keys)
{
    bool fn_active = is_fn_pressed();
    const uint8_t (*active_keymap)[NUM_COLS] = fn_active ? fn_keymap : keymap;
    uint8_t key_count = 0;

    for (int row = 0; row < NUM_ROWS; row++) {
        // Set current row LOW
        gpio_put(row_pins[row], 0);
        sleep_us(1);  // Small delay for signal to stabilize

        // Read all columns
        for (int col = 0; col < NUM_COLS; col++) {
            bool is_pressed = !gpio_get(col_pins[col]);  // LOW = pressed

            if (is_pressed) {
                uint8_t keycode = active_keymap[row][col];

                // Don't add FN key or NONE key
                if (keycode != HID_KEY_FN && keycode != HID_KEY_NONE) {
                    // Add to array if there's space
                    if (key_count < max_keys) {
                        keycodes[key_count++] = keycode;
                    }
                }
            }
        }

        // Set current row back to HIGH
        gpio_put(row_pins[row], 1);
    }

    return key_count;
}

int main()
{
    board_init();
    tud_init(BOARD_TUD_RHPORT);

    // Initialize LED
    gpio_init(LED_PIN);
    gpio_set_dir(LED_PIN, GPIO_OUT);

    // Initialize row pins as outputs (ROW를 스캔)
    for (int i = 0; i < NUM_ROWS; i++) {
        gpio_init(row_pins[i]);
        gpio_set_dir(row_pins[i], GPIO_OUT);
        gpio_put(row_pins[i], 1);  // HIGH by default
    }

    // Initialize column pins as inputs with pull-up (COLUMN을 읽음)
    for (int i = 0; i < NUM_COLS; i++) {
        gpio_init(col_pins[i]);
        gpio_set_dir(col_pins[i], GPIO_IN);
        gpio_pull_up(col_pins[i]);
    }

    uint32_t last_change_time = 0;

    while (true) {
        tud_task();

        uint32_t now = board_millis();

        // Debouncing and sending HID report
        if ((now - last_change_time) >= 20) {
            if (tud_hid_ready()) {
                uint8_t keycodes[6] = {0};
                uint8_t key_count = scan_matrix(keycodes, 6);

                tud_hid_keyboard_report(0, 0, keycodes);
                gpio_put(LED_PIN, key_count > 0);
            }
            last_change_time = now;
        }
    }
}

uint16_t tud_hid_get_report_cb(uint8_t instance, uint8_t report_id, hid_report_type_t report_type, uint8_t* buffer, uint16_t reqlen)
{
  (void) instance;
  (void) report_id;
  (void) report_type;
  (void) buffer;
  (void) reqlen;

  return 0;
}

void tud_hid_set_report_cb(uint8_t instance, uint8_t report_id, hid_report_type_t report_type, uint8_t const* buffer, uint16_t bufsize)
{
  (void) instance;
  (void) report_id;
  (void) report_type;
  (void) buffer;
  (void) bufsize;
}

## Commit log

2025-11-05 feat: design pcb
    [keyboard.kicad_pcb, keyboard.kicad_sch, keyboard.step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]
2025-11-05 docs: add schematic svg
2025-11-05 chore: resize pcb paper
    [keyboard.kicad_pcb]
2025-11-05 docs: add pcb.png
2025-11-05 feat: add track and cut line to step
2025-11-10 feat: add gerbers
    [bom.csv, designators.csv, positions.csv]
2025-11-11 feat: add fusion and stl
    [Case.f3z, Outer.stl, Plate.stl]
2025-11-15 fix: shallow wall in case
    [Case.f3z, Outer.stl]
2025-11-15 feat: init pico firmware
2025-11-22 feat: blink led when z pressed
2025-11-22 fix: hid report format
    [firmware.c]
2025-11-22 feat: make switch as z key
2025-12-01 feat: add hole for bootsel btn
    [Case.f3z, Outer.stl]
